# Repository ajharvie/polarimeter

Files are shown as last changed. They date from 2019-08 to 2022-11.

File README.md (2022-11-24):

Firmware and supporting data for a polarimeter as described in Scientific Reports: **A high-resolution polarimeter formed from inexpensive optical parts** https://doi.org/10.1038/s41598-020-61715-7

Code for the microcontroller can be found in the "Arduino Code" folder. The folder "Frontend tool" provides a simple python GUI for interfacing with the polarimeter. 
"Design files" contains .stl format files for custom parts used to build the polarimeter, as well as .brd files for circuit boards.
"Supporting Files" contains code for recording optical signals and simulating polarimeter behaviour, as well as data files for the plots presented in the paper.

*A.J. Harvie, T.W. Phillips and J.C. deMello*

**A new version - OPol - has been released. You can find the design files here: https://github.com/OpenPolarimeter/OPol, and a publication describing its build and use here: https://doi.org/10.1002/cmtd.202000057**

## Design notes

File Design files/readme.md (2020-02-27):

Design files for custom parts for the polarimeter, including:

1) .stl format files for the flow cell and mounting block
2) .stl format file for the 3d printed part for mounting the optical sensors onto an optical post
3) .brd and .sch files for a PCB to interface with the OPT101s (use of 8-pin DIP sockets recommended)
4) .stl format file for the 3d printed part for mounting the microcontroller
5) .brd and .sch files for a PCB for connections to the µC (and power passthrough)
6) A technical drawing of the flow cell dimensions

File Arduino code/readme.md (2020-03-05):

Arduino firmware for the polarimeter. Two versions are presented:
1) TeensyPolarimeterv1_0 is the version used to obtain the data in the paper. It is written for a deprecated version of teensyduino and should not be used.
2) TeensyPolarimeterv1_1 is compatible with the current version (1.51) of teensyduino. It will work on a Teensy 3.6 or Teensy 4.0.

Requires Arduino and the Teensyduino add-on (current version 1.51) to use.

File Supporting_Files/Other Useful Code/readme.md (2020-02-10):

"Demo_Figure.m" contains matlab code to generate Fig 2. Requires the function sdft_plug.m to work.

"Simulator.m" is the code used to simulate polarimeter behaviour in the supporting info. It works over 1000000 samples so takes a long time to run!

"Polarimeter_Signals.ino" is arduino code which outputs the measured and corrected optical signals recorded by the photodiodes, and scaled by the reference signal recorded by the light-frequency converter.

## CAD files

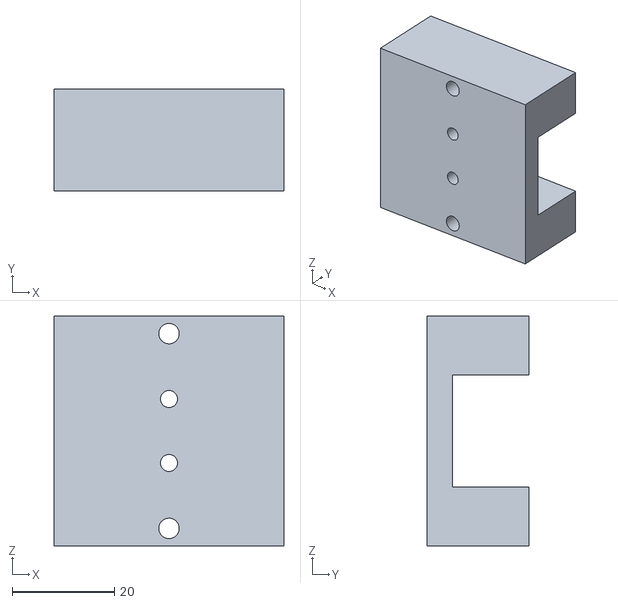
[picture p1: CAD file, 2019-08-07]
Design files/Flow_Cell_Mounting_Block.stl
45.0 x 20.0 x 45.0

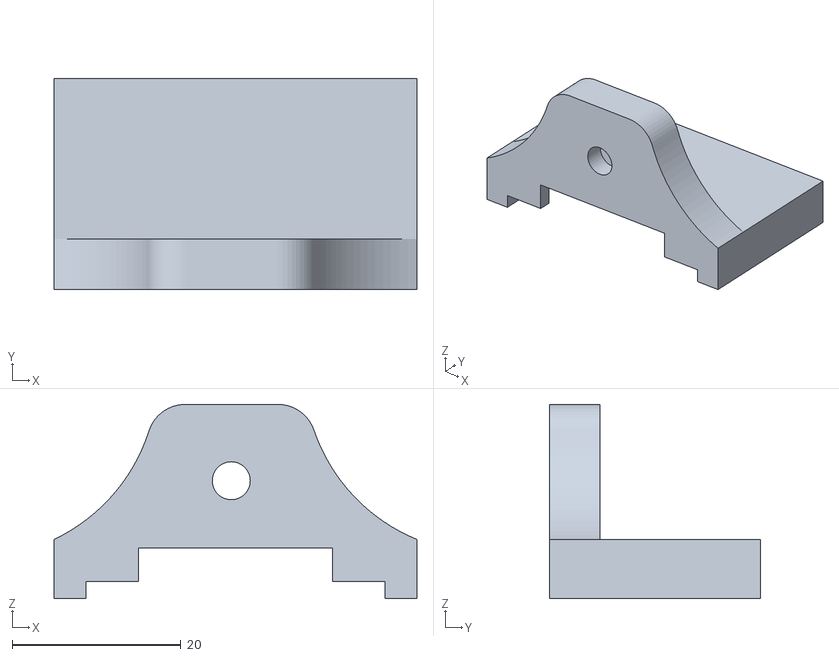
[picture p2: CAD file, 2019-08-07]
Design files/Sensor_Board_Holder.stl
43.0 x 25.0 x 23.0

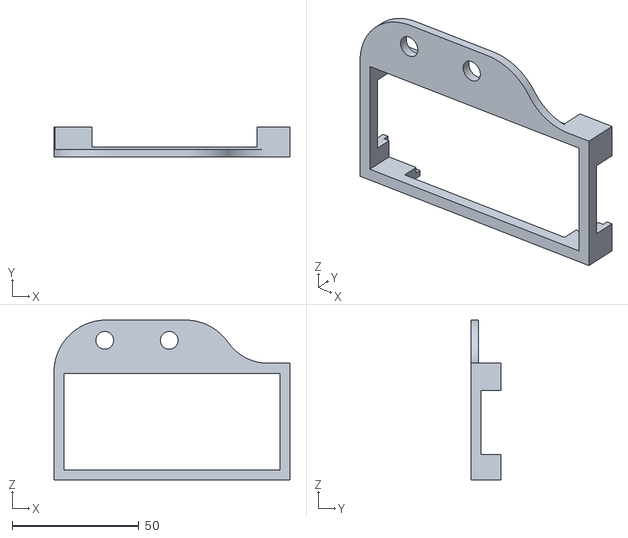
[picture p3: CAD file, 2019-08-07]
Design files/Teensy_Board_Holder.stl
93.0 x 12.0 x 63.0

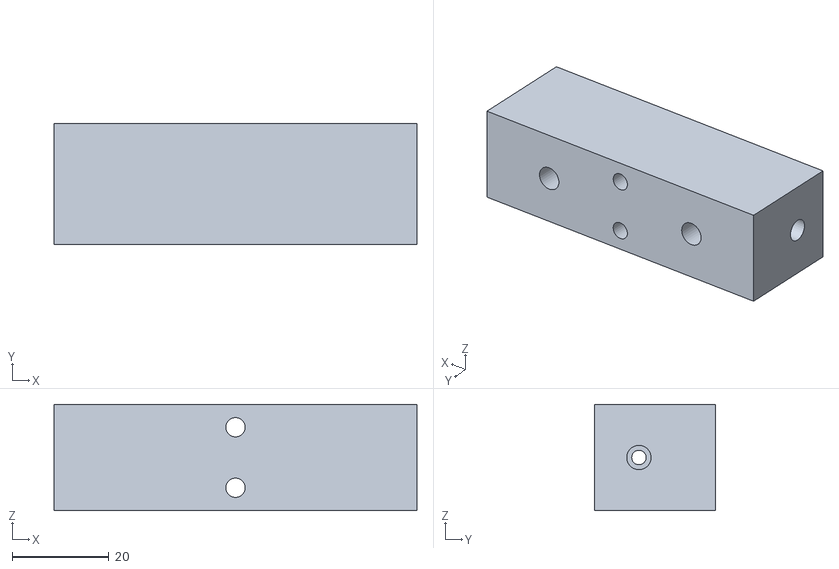
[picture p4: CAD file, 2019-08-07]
Design files/Flow_Cell.stl
75.0 x 25.0 x 22.0

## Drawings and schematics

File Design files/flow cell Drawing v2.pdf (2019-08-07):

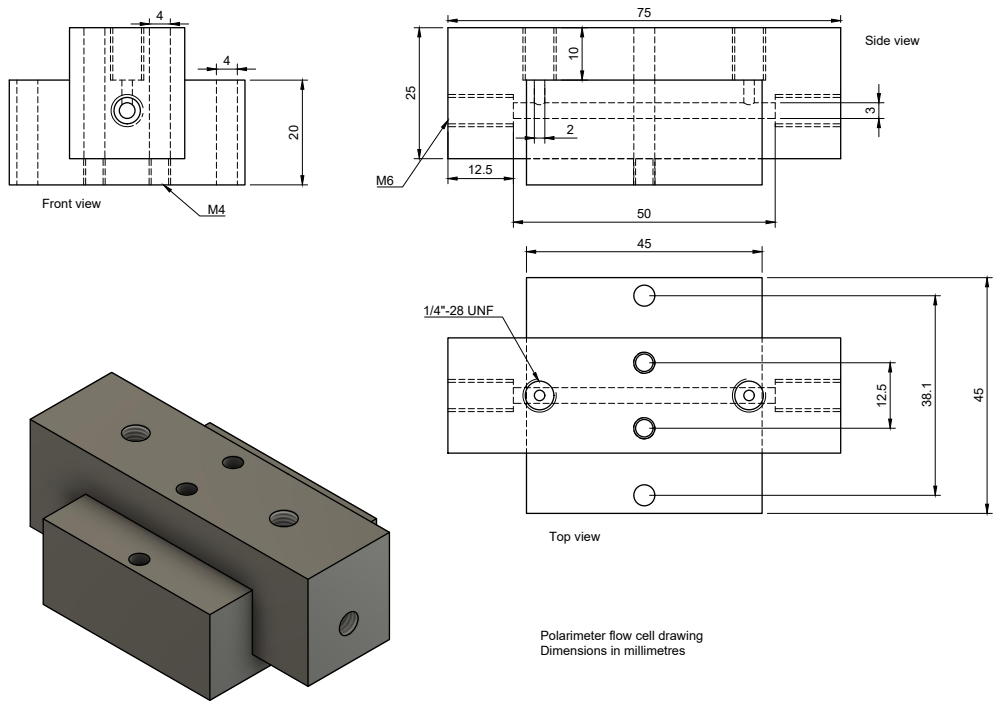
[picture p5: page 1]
1/4"-28 UNF; Front view; Side view; Top view

Polarimeter flow cell drawing
Dimensions in millimetres

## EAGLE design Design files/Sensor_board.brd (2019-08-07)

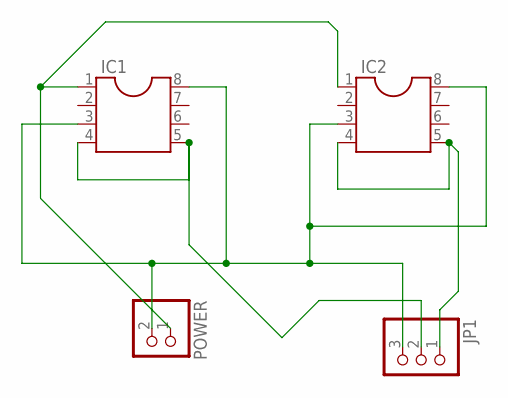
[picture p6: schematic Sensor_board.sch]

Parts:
IC1, IC2: DIL8S; SOCKET-08
JP1: PINHD-1X3; 1X03
POWER: PINHD-1X2; 1X02

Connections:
unnamed: IC1.3, IC1.8, IC2.3, IC2.8, JP1.3, POWER.2
unnamed: IC1.1, IC2.1, POWER.1
unnamed: IC1.4, IC1.5, JP1.2
unnamed: IC2.4, IC2.5, JP1.1

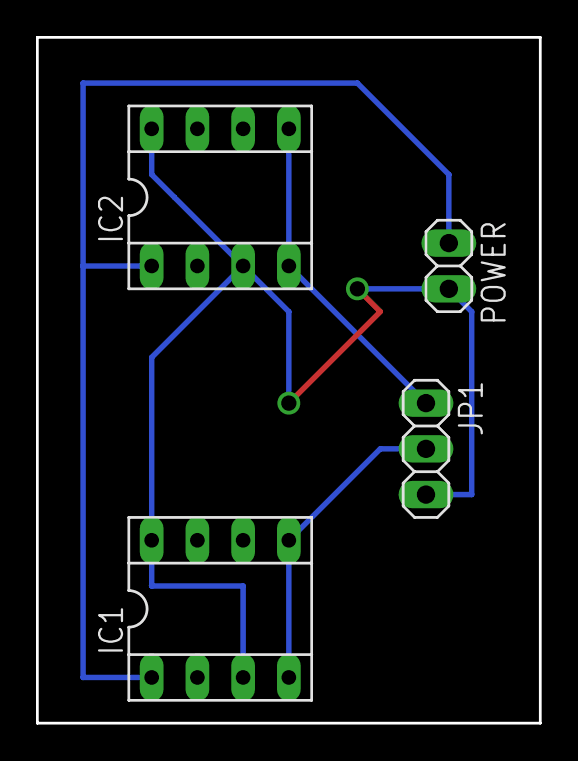
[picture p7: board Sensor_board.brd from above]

Board: 2 copper layers, 27.9 x 38.1 mm, 4 parts (0 on the bottom side), 4 nets.

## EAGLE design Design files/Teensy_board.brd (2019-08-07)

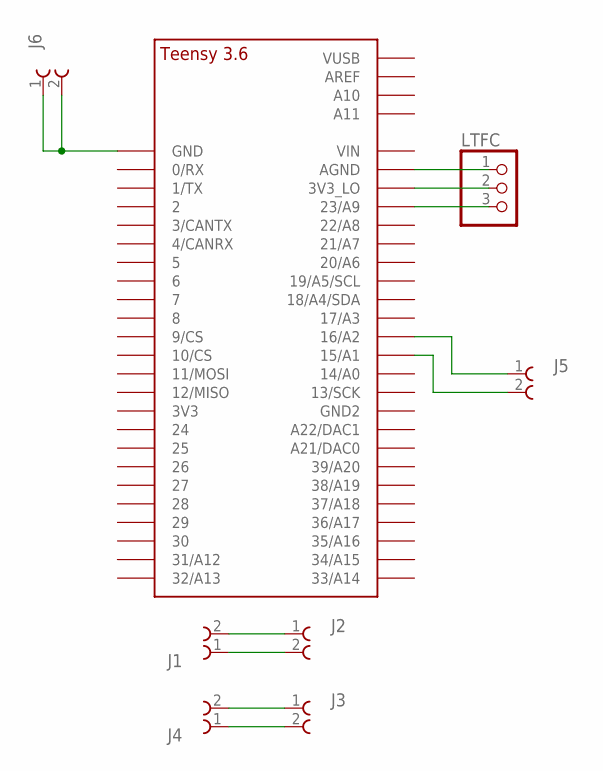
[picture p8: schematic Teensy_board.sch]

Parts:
J1, J2, J3, J4, J5, J6: 691103110002
LTFC: PINHD-1X3; 1X03
U$1: TEENSY_3.5/3.6_BASIC

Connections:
unnamed: LTFC.1, U$1.AGND
unnamed: LTFC.2, U$1.3V3_LO
unnamed: LTFC.3, U$1.23/A9
unnamed: J5.2, U$1.15/A1
unnamed: J5.1, U$1.16/A2
unnamed: J1.2, J2.1
unnamed: J1.1, J2.2
unnamed: J3.1, J4.2
unnamed: J3.2, J4.1
SIGNAL_G: J6.1, J6.2, U$1.GND

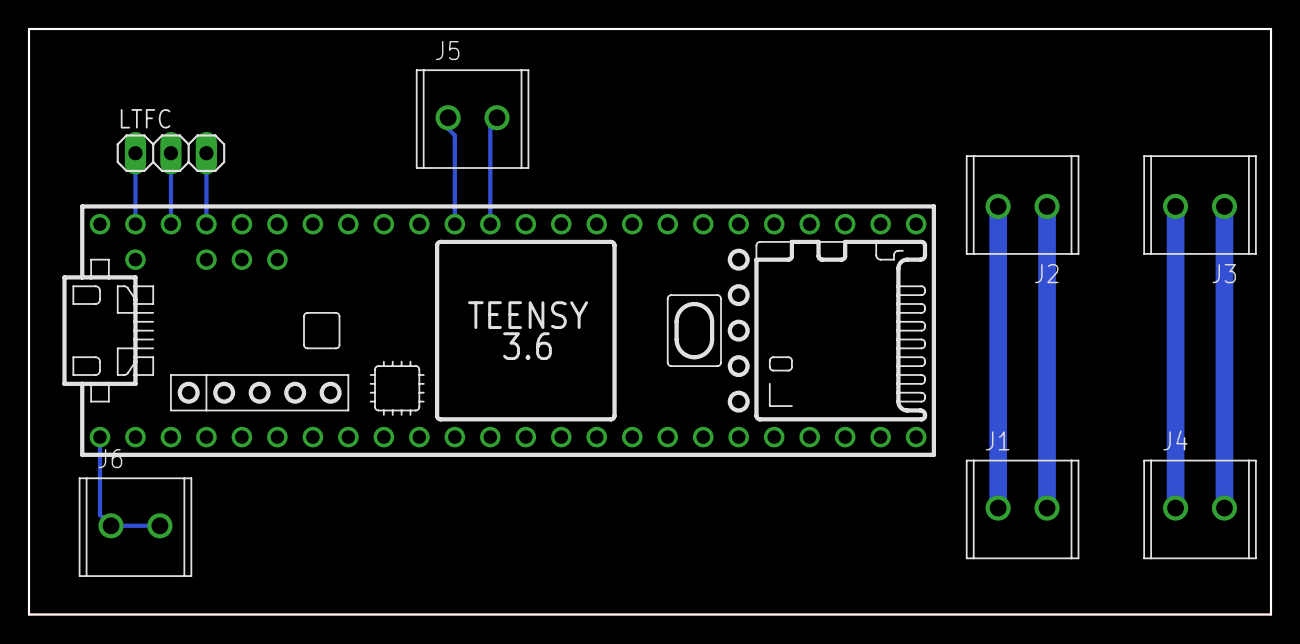
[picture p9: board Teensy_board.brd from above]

Board: 2 copper layers, 88.9 x 41.9 mm, 8 parts (0 on the bottom side), 10 nets.

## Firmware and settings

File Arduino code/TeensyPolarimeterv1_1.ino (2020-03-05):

/*  
MIT License
Copyright (c) 2020 Andrew Harvie
Permission is hereby granted, free of charge, to any person obtaining a copy
of this software and associated documentation files (the "Software"), to deal
in the Software without restriction, including without limitation the rights
to use, copy, modify, merge, publish, distribute, sublicense, and/or sell
copies of the Software, and to permit persons to whom the Software is
furnished to do so, subject to the following conditions:
The above copyright notice and this permission notice shall be included in all
copies or substantial portions of the Software.
THE SOFTWARE IS PROVIDED "AS IS", WITHOUT WARRANTY OF ANY KIND, EXPRESS OR
IMPLIED, INCLUDING BUT NOT LIMITED TO THE WARRANTIES OF MERCHANTABILITY,
FITNESS FOR A PARTICULAR PURPOSE AND NONINFRINGEMENT. IN NO EVENT SHALL THE
AUTHORS OR COPYRIGHT HOLDERS BE LIABLE FOR ANY CLAIM, DAMAGES OR OTHER
LIABILITY, WHETHER IN AN ACTION OF CONTRACT, TORT OR OTHERWISE, ARISING FROM,
OUT OF OR IN CONNECTION WITH THE SOFTWARE OR THE USE OR OTHER DEALINGS IN THE
SOFTWARE.
Software for Teensy-powered polarimeter. Performs sliding DFT on periodic intensities 
from two OPT101s, with reference for laser intensity on a light-frequency converter
(TSL235R-LF). After "initialisation" step, where sDFT bins are filled, peaks are located 
to find the shared fundamental frequency of the periodic  signals. The sDFT is then 
continuously updated at the peak location only, and a value of the phase difference 
between the two signals is calculated at the peak and output over serial connection.
Uses single-precision floats to take advantage of Teensy 3.6's FPU.
Sliding DFT libary adapted slightly from the implementation by Bronson Philippa 
https://github.com/bronsonp/SlidingDFT
ADC library for Teensy by Pedro Villanueva, pedvide https://github.com/pedvide/ADC 
*/


#include "sliding_dft_narrow.h"
#include <math.h>
#include <ADC.h>
#define pi 3.14159265358979

//Choose sample rate in microseconds (600)
#define looptime 600

//Choose update rate (number of samples between each output)
#define up_rate 64 

// Number of initialisation samples
#define number_loops 1025

//LED pin
#define ledPin 13

//Pin for light-frequency converter input
#define ltfPin 23

//Pins for OPT101s 
#define pin1 A1
#define pin2 A2

//Smoothing parameter for L-F converter.
float alpha = 0.01;

//Smoothing parameter for output filter (multiplier = 1 for approx 6s time constant)
float lambda = 1*0.0128;

float min_lambda = 1-lambda;

//Variables///////////////////////////
int i;
int up_index = 0;
int peak_location = 0; 
int initialiser0[number_loops];
int initialiser1[number_loops];
int initialiser_refs[number_loops];
unsigned long current_time = 0;
unsigned long old_time = 0;
unsigned long gap;
float oldref = 0.0;
float ref_value; 
float phase1;      
float phase2;
float lag;
float re1;
float re2;
float im1;
float im2;
bool wait = true;
bool first = true;
float checkmag;
float maxmag = 0.0;
volatile int count = 0;
int lastcount = 0;
int grabcount = 0;
float peakLeft;
float peakCentre;
float peakRight;
float gapLeft;
float gapCentre;
float gapRight;
float delta;
int stabilised = 0;
float filtered;


// wow look at all these g l o b a l s //
/////////////////////////////////////////

//ADC object
ADC *adc = new ADC();

// Intitialise 2 DFTs in parallel. 
static SlidingDFT<float, 1024> dft1;
static SlidingDFT<float, 1024> dft2;

//ISR for Light-Frequency converter
void irq1(){
  ++count;
}

//Function to fill up sDFT
void initialise(){
  
  digitalWrite(ledPin, HIGH); //LED on for setup phase
  
  // For "initialisation" phase - loop fills arrays
  for (i=0; i < (number_loops); ++i){
    wait = true;

    //timing loop. Don't use delay() as it doesn't always play nicely with interrupts
    while(wait == true){
      current_time = micros();
      gap = current_time - old_time;
      if (gap > looptime){
        old_time = current_time;      
        wait = false;
        break;
      }
    }
    
    //Get values from ADCs and l-f converter
    ADC::Sync_result result = adc->analogSyncRead(pin1, pin2);
    grabcount = count;
    count = 0;
    
    initialiser_refs[i] = grabcount;
    initialiser0[i] = result.result_adc0;
    initialiser1[i] = result.result_adc1;
  }

  //apply corrections and update sDFTs
  for (i=0; i < (number_loops); ++i){
    float voltage0 = (float)initialiser0[i] / (float)initialiser_refs[i];               
    float voltage1 = (float)initialiser1[i] / (float)initialiser_refs[i];
    dft1.update(voltage0);
    dft2.update(voltage1);      
  }
  
  //Find max. Starts at bin 2 to avoid spurious signal at 0 frequency              
  for (i=2; i<number_loops/2; ++i){ 
    std::complex<float> DC_bin = dft1.dft[i];
    re1 = DC_bin.real();
    im1 = DC_bin.imag();
    checkmag = sqrt((re1*re1)+(im1*im1));
    
    if (checkmag > maxmag){
      peak_location = i;
      maxmag = checkmag;
    }
  }

  //interpolating for true freq - 3 bins around peak
  std::complex<float> leftBin = dft1.dft[peak_location-1];
  std::complex<float> centreBin = dft1.dft[peak_location];
  std::complex<float> rightBin = dft1.dft[peak_location+1];
  //magnitudes
  peakLeft = abs(leftBin);
  peakCentre = abs(centreBin);
  peakRight = abs(rightBin);
  // Interpolate for peak
  delta = 2*((peakRight-peakLeft)/(2*peakCentre+peakLeft+peakRight));
  
  digitalWrite(ledPin, LOW); //LED off after initialisation step
}

void setup() {
  pinMode(ledPin, OUTPUT);
  pinMode(ltfPin, INPUT);
  attachInterrupt(digitalPinToInterrupt(ltfPin), irq1, RISING);
  Serial.begin(9600); 
  delay(50);

  //run function that fills sDFTs and finds peak
  initialise();
  
}

void loop() {

  //"Output" phase
     
  wait=true;
  
  //timing circuitry    
  while(wait==true){     
    current_time = micros();
    gap = current_time - old_time;
    if (gap > looptime){
      old_time = current_time;
      wait = false;
      break;
    }
  }
  
  //Get values from ADCs and l-f converter
  ADC::Sync_result result = adc->analogSyncRead(pin1, pin2);
  grabcount = count;
  count = 0;

  //Exponential smoothing on light-frequency converter reading
  if (first==true){
    ref_value = (float)grabcount;
  }
  else{
    ref_value = ((float)grabcount * alpha) + ((1.0 - alpha)*oldref);
  }
  
  int value0 = result.result_adc0; 
  int value1 = result.result_adc1; 
      
   //Apply correction
  float voltage0 = (float)value0 / ref_value;             
  float voltage1 = (float)value1 / ref_value;  

  //Update sDFT around peak location only
  dft1.updatepeak(voltage0, peak_location);
  dft2.updatepeak(voltage1, peak_location);
  
  //Extracting phase data at peak location
  if(delta > 0.0){ //max to rhs of peak
    gapCentre = arg(dft2.dft[peak_location])-arg(dft1.dft[peak_location]);
    gapRight = arg(dft2.dft[peak_location + 1])-arg(dft1.dft[peak_location + 1]);
    
    if (gapCentre < 0.0){
      gapCentre = gapCentre + 2*pi;
    }
    if (gapRight < 0.0){
      gapRight = gapRight + 2*pi;
    }
    
    lag = gapCentre + delta*(gapRight - gapCentre); //linear interpolation of phase

 }
  else{ //to LHS of peak
    gapCentre = arg(dft2.dft[peak_location])-arg(dft1.dft[peak_location]);
    gapLeft = arg(dft2.dft[peak_location - 1])-arg(dft1.dft[peak_location - 1]);

    if (gapCentre < 0.0){
      gapCentre = gapCentre + 2*pi;
    }
    if (gapLeft < 0.0){
      gapLeft = gapLeft + 2*pi;
    }
  
    lag = gapCentre - delta*(gapLeft - gapCentre);

 }

  oldref = ref_value;
  first = false;

  lag = lag*(180.0/pi); //convert to degrees
  
  if (lag < 0){ 
    lag = lag + 360.0; 
  }

  //don't output first 1024 samples
  if (stabilised < 1024){
    up_index = 0;
    ++stabilised;
    filtered = lag;
  }

  
  ++up_index;
  if (up_index == up_rate){
    
    filtered = filtered*min_lambda + lambda*lag;
    Serial.println(filtered,5);

    up_index = 0;
  }
   
}

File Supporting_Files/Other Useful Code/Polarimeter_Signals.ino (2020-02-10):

#include <ADC.h>

#define ledPin 13
#define ltfPin 23

int current_time = 0;
int old_time = 0;
int gap = 0;
int looptime = 600;
bool wait = true;
bool first = true;
volatile int count = 0;
int grabcount;
float corr;
float lastcorr;
float alpha = 0.01;


ADC *adc = new ADC();

void irq1(){
  ++count;
}

void setup() {
  attachInterrupt(digitalPinToInterrupt(ltfPin), irq1, RISING); 
  adc->setResolution(12,0);
  adc->setResolution(12,1);
  //sampling speed
  adc->setSamplingSpeed(ADC_SAMPLING_SPEED::VERY_LOW_SPEED, 0);
  adc->setSamplingSpeed(ADC_SAMPLING_SPEED::VERY_LOW_SPEED, 1);
  pinMode(ledPin, OUTPUT); 
  // serial port for monitoring
  Serial.begin(9600);
}

void loop() {

  while(wait == true){
    current_time = micros();
    gap = current_time - old_time;
    if (gap > looptime){
      old_time = current_time;      
      wait = false;
      break;
    }
  }
  
  ADC::Sync_result result = adc->analogSyncRead(A1, A2);
  grabcount = count;
  count = 0;
  int value0 = result.result_adc0; 
  int value1 = result.result_adc1; 
  if(first == true){
    corr = (float)grabcount;
    lastcorr = corr;    
  }
  else{
    corr = ((float)grabcount * alpha) + ((1.0 - alpha)*lastcorr);
  }
  
  float voltage0 = value0/corr;
  float voltage1 = value1/corr; 

  Serial.print(voltage0);
  Serial.print(" ");
  Serial.println(voltage1);

  wait = true; 
  first = false; 
  
}

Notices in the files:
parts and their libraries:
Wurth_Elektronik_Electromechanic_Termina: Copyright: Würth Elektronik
